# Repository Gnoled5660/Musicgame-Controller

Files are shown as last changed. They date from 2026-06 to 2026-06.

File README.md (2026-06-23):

# Musicgame-Controller

Controller_with_Case_2026-Jun-20_02-33-02PM-000_CustomizedView34039528250_png

# Description
This is an arcade like controller, designed for the Musicgame by bakedcloudz (GitHub Repo: https://github.com/wuelaineyuan-bit/MUSICGAME). It has four interactive buttons and one joystick. Next to these features, it also has a speaker on the side and a tft display. While the controller is inactive or is not being used, it will play a retro arcade like music in the background. All this is powered by a Raspberry Pi Pico 2.

# Motivation
The reason we designed this was because bakedcloudz project lacked of an interactive controller for her arcade game. Therefore, we wanted to design another controller for that project. This project is a sub project of the main project MUSICGAME (GitHub Repo: https://github.com/wuelaineyuan-bit/MUSICGAME). 

# PCB and Schematic
The PCB and schematic was made with KiCAD. Schematic is rather simple: Connect the pins to the buttons and joysticks. As almost every Pico 2 pin is a GPIO pin, almost every pin could be used to connect to the amplifier and tft module. 

Bildschirmfoto 2026-06-20 um 15 15 44

This PCB is a rather simple PCB, where the premade modules are soldered on top of it. There are no components that need to be preassembled. All the components are big enough to be soldered by hand. 

Bildschirmfoto 2026-06-20 um 15 12 18

This PCB is a two layer PCB, where the red tracks function as signal tracks and the blue tracks as power supply tracks.

Bildschirmfoto 2026-06-20 um 15 14 18

# Firmware
The firmware was written in micropython. Most of libraries are standard libraries provided by micropico. However, we had to download an external library for the tft display. The program begins with playing a retro music until one button is clicked. Then, it stops playing the music in a loop and starts listening to the actions that the user might take. Once a button or the joystick is pressed, it sends a message to the computer with the print() function. The other projects code has to read the lines with serial.readline() to decide which actions to make next.

# Assembling
There are a few components that need to be screwed on to the board. These components include the PCB, the joystick and the display. Because of that, we designed some holes, where heat threaded inserts can be placed. All components use M3 screws besides the joystick. The joystick requires M5 screws. The buttons can be simply pressed into the holes, which means it doesnt require any screws. 

Bildschirmfoto 2026-06-20 um 15 48 46

Bildschirmfoto 2026-06-20 um 15 49 10

Many components need to be soldered on to the PCB too. It is recommended to use header pins between the Pico 2 board and the PCB. After everything is soldered, you need the connection cables to connect the PCB with the buttons and joysticks. Another cable is used to connect the amplifier with the speaker.

Bildschirmfoto 2026-06-20 um 15 53 17

Depending on whether you want to color the music notes, there two versions of this controller. As a usual 3D printer cannot print two colors at the same time, the music notes have to be painted later by hand, if they should be colored black.

Bildschirmfoto 2026-06-19 um 22 34 00
Bildschirmfoto 2026-06-19 um 22 34 19

# Zine
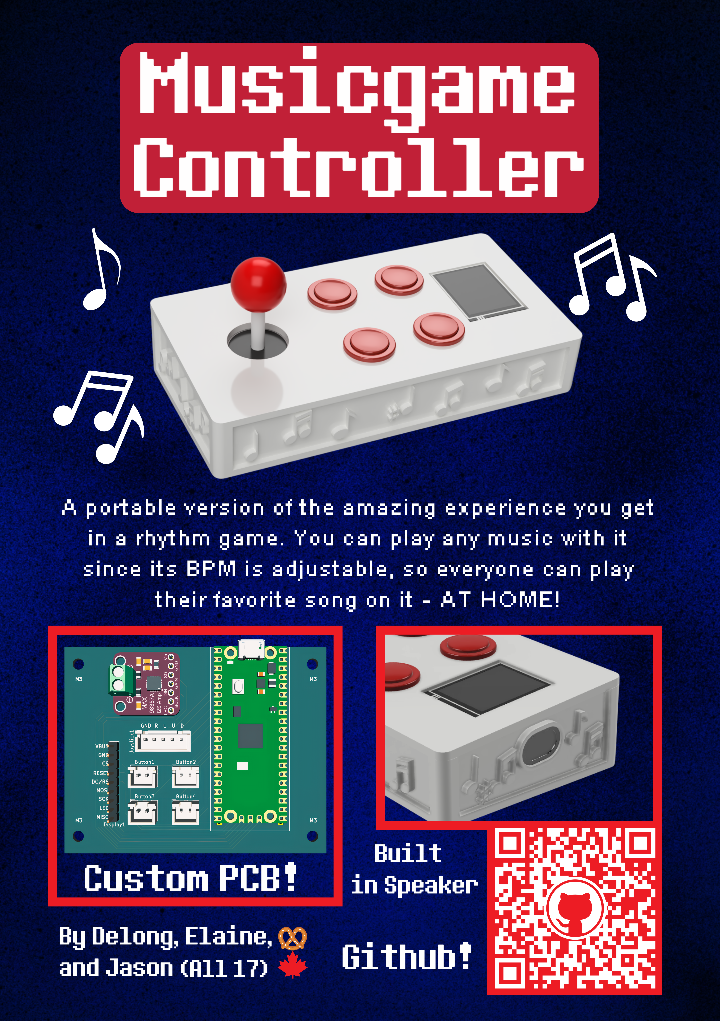
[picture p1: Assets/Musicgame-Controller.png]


# BOM
|Name |Description |Links |Quantity|Cost |
|---|---|---|---|-----|
|PCB |Printed Circuit Board |https://jlcpcb.com |1 |6 |
|Speaker |8Ohm 1W Speaker |https://botland.de/analoge-lautsprecher/19458-lautsprecher-1w-8ohm-30x20x5mm-adafruit-4227-5904422354848.html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 |1 |3.20 |
|MAX98357A |Amplifier |https://www.amazon.de/Verstärker-Verstärkerplatine-Elektronische-Enthusiasten-Ingenieure/dp/B0F1TRSD2N/ref=asc_df_B0F1TRSD2N?mcid=b3cc78920c783042ac17388eb574bcae&th=1&psc=1&tag=googshopde-21&linkCode=df0&hvadid=751200241164&hvpos=&hvnetw=g&hvrand=557849342057074083&hvpone=&hvptwo=&hvqmt=&hvdev=c&hvdvcmdl=&hvlocint=&hvlocphy=9192175&hvtargid=pla-2419607785174&psc=1&hvocijid=557849342057074083-B0F1TRSD2N-&hvexpln=0|1 |8 |
|Pico 2 |Microcontroller |https://www.reichelt.de/de/de/shop/produkt/raspberry_pi_pico_2_rp235x_cortex-m33_microusb-383358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 |1 |5.14 |
|Arcade Button |Button |https://www.berrybase.de/mini-arcade-button-24mm/farbe-rot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 |4 |4.13 |
|Joystick |Joystick to control direction|https://de.aliexpress.com/item/1005006881757851.html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€%214%2C69€%21%21%21%21%21%40211b6c1717819569630011453e4670%2112000038607187018%21btfpre%21%21%21%211%210%21&pvid=210f2bc9-ea8b-413f-9403-466b57ef5987&afTraceInfo=1005006881757851__pc__c_ppc_item_bridge_pc_same_wf__r6YWpYS__1781956963362&gatewayAdapt=glo2deu |1 |12.61|
|5 Pin JST-XH |Receptacle for Joystick |https://www.reichelt.de/de/de/shop/produkt/jst_-_stiftleiste_gerade_1x5-polig_-_xh-185076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 |1 |0.34 |
|2 Pin JST-XH |Receptacle for Buttoms |https://www.berrybase.de/ph2.0-buchse-printmontage-gerade-2-pin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 |4 |0.46 |
|2 Pin JST-XH cable |Cable |https://www.berrybase.de/kabel-mit-jst-xh-2.54mm-steckverbinder-awg26-20cm/pinanzahl-2-pin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 |4 |1.60 |
|5 Pin JST-XH cable |Cable |https://www.berrybase.de/kabel-mit-jst-xh-2.54mm-steckverbinder-awg26-20cm/pinanzahl-5-pin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 |1 |0.57 |
|Header Pin |2.54mm Header Pin |https://www.digikey.de/de/products/detail/amphenol-icc-fci-/10129378-920003BLF/7915971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 |1 |0.52 |
|Heated threaded inserts|M3x4mmx5mm |https://www.berrybase.de/bossard-bn1052-gewindeeinsatz-messing-m3-laenge-5-8mm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 |8 |2.58 |
|Heated threaded inserts|M5x9mmx5mm |https://www.berrybase.de/bossard-bn1052-gewindeeinsatz-messing-m5-laenge-9-5mm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 |4 |1.28 |
|M3 |screws |https://www.berrybase.de/makerbeam-linsenkopfschrauben-fuer-15x15-makerbeamxl-openbeam-m3x6mm-innensechskant-100-stueck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 |8 |6 |
|M5 |screws |https://www.thomann.de/de/km_m5_rack_screw_pack.htm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 |4 |4 |
|Filament |Whole Case | |1 |8.93 |
|total | | | |63.19|

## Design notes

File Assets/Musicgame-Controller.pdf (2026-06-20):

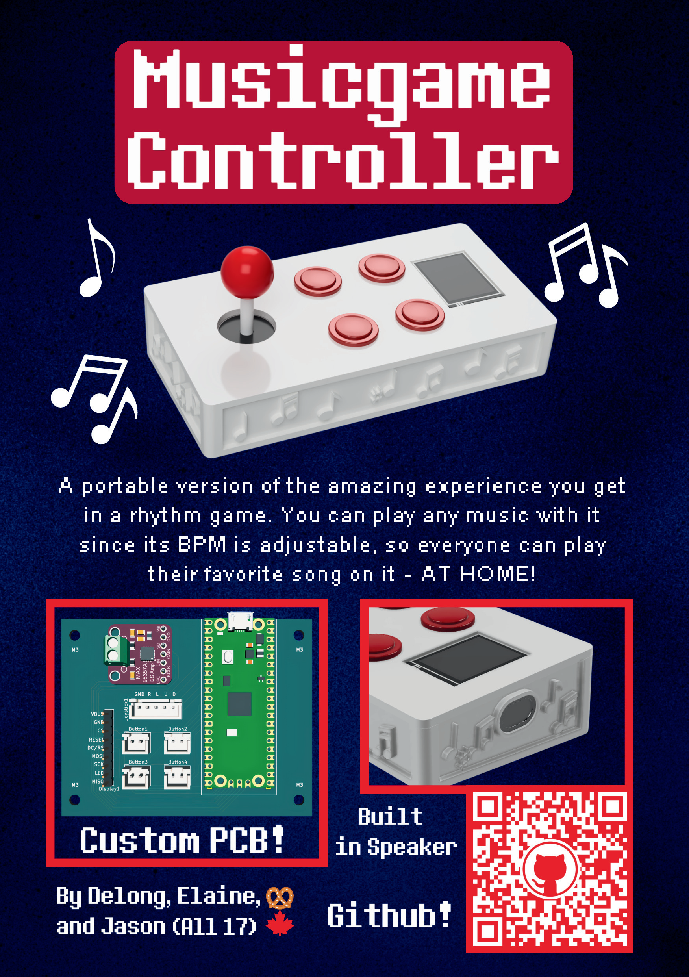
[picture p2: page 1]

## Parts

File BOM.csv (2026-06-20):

Name | Description | Links | Quantity | Cost
PCB | Printed Circuit Board | https://jlcpcb.com | 1 | 6
Speaker | 8Ohm 1W Speaker | https://botland.de/analoge-lautsprecher/19458-lautsprecher-1w-8ohm-30x20x5mm-adafruit-4227-5904422354848.html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 | 1 | 3.20
MAX98357A | Amplifier | https://www.amazon.de/Verstärker-Verstärkerplatine-Elektronische-Enthusiasten-Ingenieure/dp/B0F1TRSD2N?mcid=b3cc78920c783042ac17388eb574bcae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 | 1 | 8
Pico 2 | Microcontroller | https://www.reichelt.de/de/de/shop/produkt/raspberry_pi_pico_2_rp235x_cortex-m33_microusb-383358?PROVID=2788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 | 1 | 5.14
Arcade Button | Button | https://www.berrybase.de/mini-arcade-button-24mm/farbe-rot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 | 4 | 4.13
Joystick | Joystick to control direction | https://de.aliexpress.com/item/1005006881757851.html | 1 | 12.61
5 Pin JST-XH | Receptacle for Joystick | https://www.reichelt.de/de/de/shop/produkt/jst_-_stiftleiste_gerade_1x5-polig_-_xh-185076?PROVID=2788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 | 1 | 0.34
2 Pin JST-XH | Receptacle for Buttoms | https://www.berrybase.de/ph2.0-buchse-printmontage-gerade-2-pin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 | 4 | 0.46
2 Pin JST-XH cable | Cable | https://www.berrybase.de/kabel-mit-jst-xh-2.54mm-steckverbinder-awg26-20cm/pinanzahl-2-pin?gad_source=1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 | 4 | 1.60
5 Pin JST-XH cable | Cable | https://www.berrybase.de/kabel-mit-jst-xh-2.54mm-steckverbinder-awg26-20cm/pinanzahl-5-pin?gad_source=1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 | 1 | 0.57
Header Pin | 2.54mm Header Pin | https://www.digikey.de/de/products/detail/amphenol-icc-fci-/10129378-920003BLF/7915971?gclsrc=aw.ds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 | 1 | 0.52
Heated threaded inserts | M3x4mmx5mm | https://www.berrybase.de/bossard-bn1052-gewindeeinsatz-messing-m3-laenge-5-8mm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 | 8 | 2.58
Heated threaded inserts | M5x9mmx5mm | https://www.berrybase.de/bossard-bn1052-gewindeeinsatz-messing-m5-laenge-9-5mm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 | 4 | 1.28
M3 | screws | https://www.berrybase.de/makerbeam-linsenkopfschrauben-fuer-15x15-makerbeamxl-openbeam-m3x6mm-innensechskant-100-stueck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 | 8 | 6
M5 | screws | https://www.thomann.de/de/km_m5_rack_screw_pack.htm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 | 4 | 4
Filament | Whole Case |  | 1 | 8.93
total |  |  |  | 63.19

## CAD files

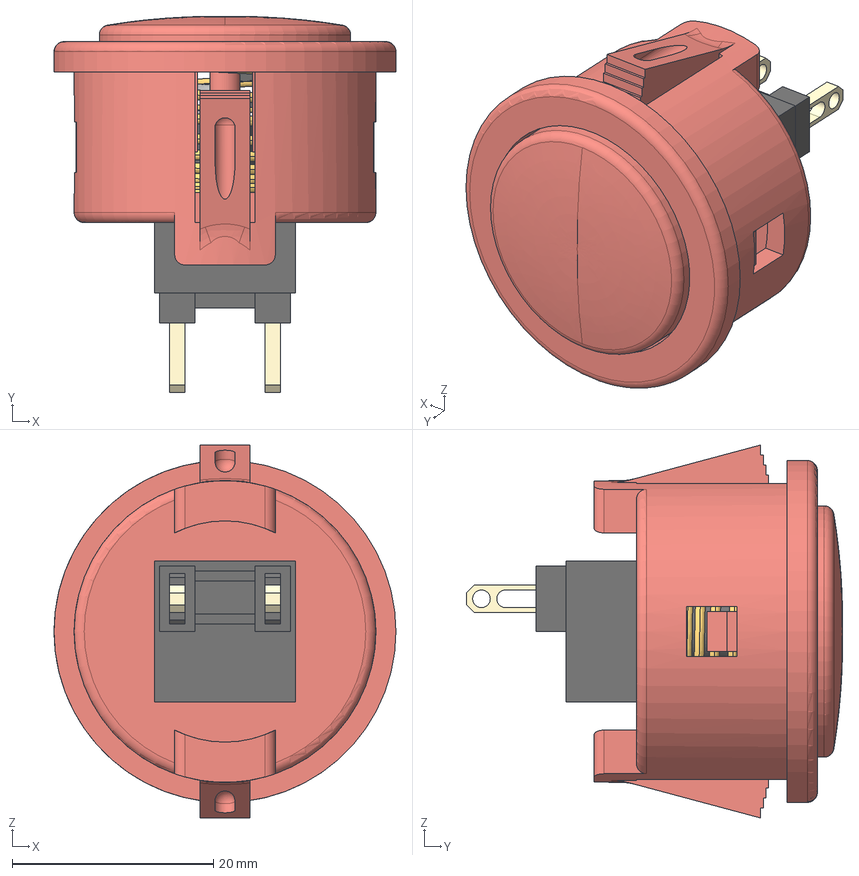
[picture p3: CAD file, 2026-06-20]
CAD/sanwa_button_00_asm v3.step
34.0 x 37.4 x 37.1 mm
SANWA_BUTTON_00
BLACK_00
SANWA_BUTTON_02
SPRING_4U_AF0

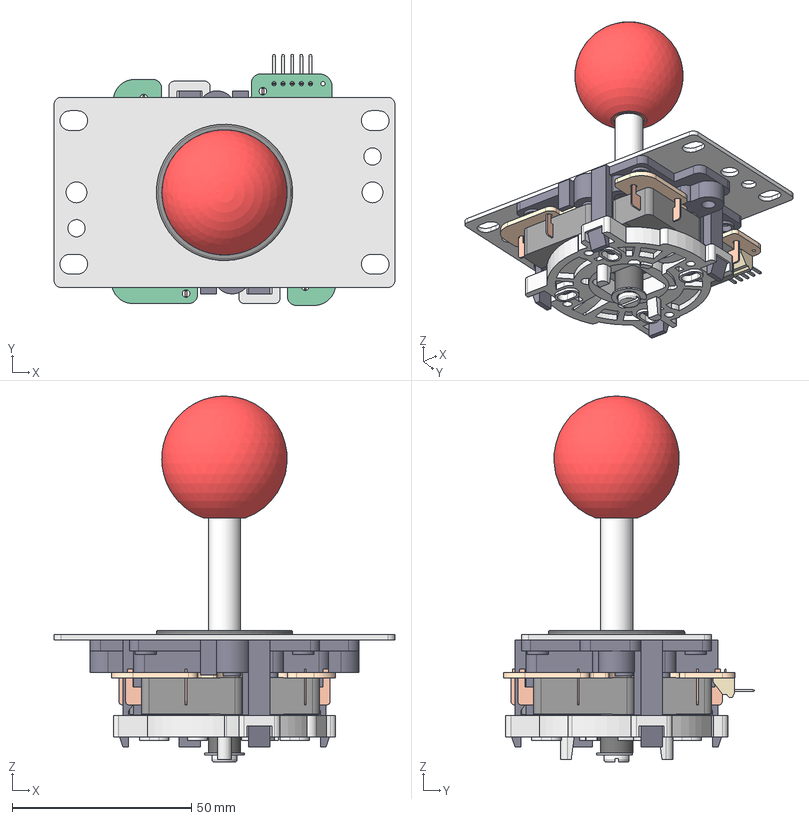
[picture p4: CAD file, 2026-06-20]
CAD/Sanwa JLF-TP-8YT 4-8Gate v1.step
95.0 x 69.9 x 102.0 mm
Connector 5P
JLF-P1 Mounting Plate
Sanwa LB-35 Balltop Dark Red
Sanwa JL-S9F Shaft
Solo Sanwa JLF Dustwasher
Sanwa LB-30 N-S Battop Adapter
Sanwa JLF P-2 Main Body
Sanwa JLF-P-4 Pivot
Push Button Arcade
Push Button Arcade_clne150
Push Button Arcade_clne151
Push Button Arcade_clne152
Sanwa JLF Actuator
Circlip
Sanwa JLF-P-6 Pressure Spring Base
Sanwa TP-MA PCB
Sanwa JLF-MW Washer
Sanwa JLF Spring
Sanwa GT-8F 4/8-Way Restrictor Plate
M3x10-Screw
M3x10-Screw001
M3x10-Screw002
M3x10-Screw003
M3-Nut
M3-Nut004
M3-Nut007
M3-Nut006
Sanwa GT Restrictor Plate

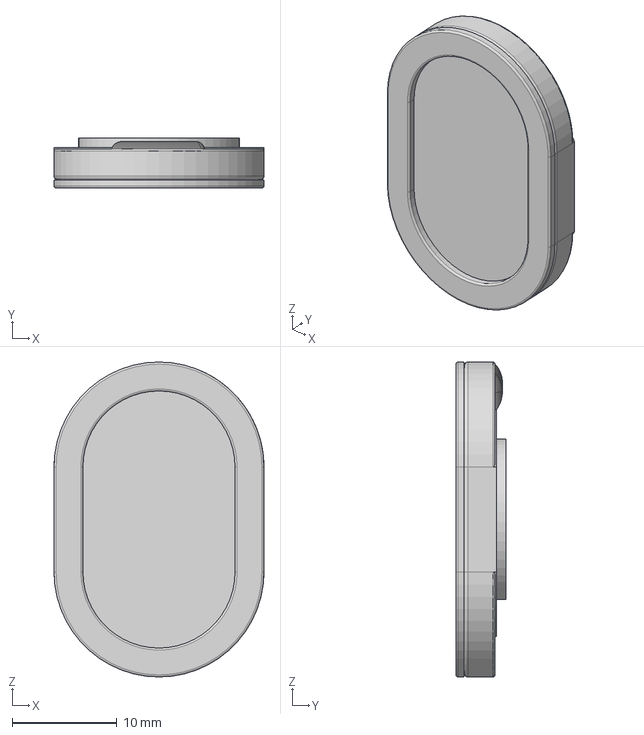
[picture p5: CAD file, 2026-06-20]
CAD/Speaker (1) v1.step
20.0 x 4.80 x 30.0 mm

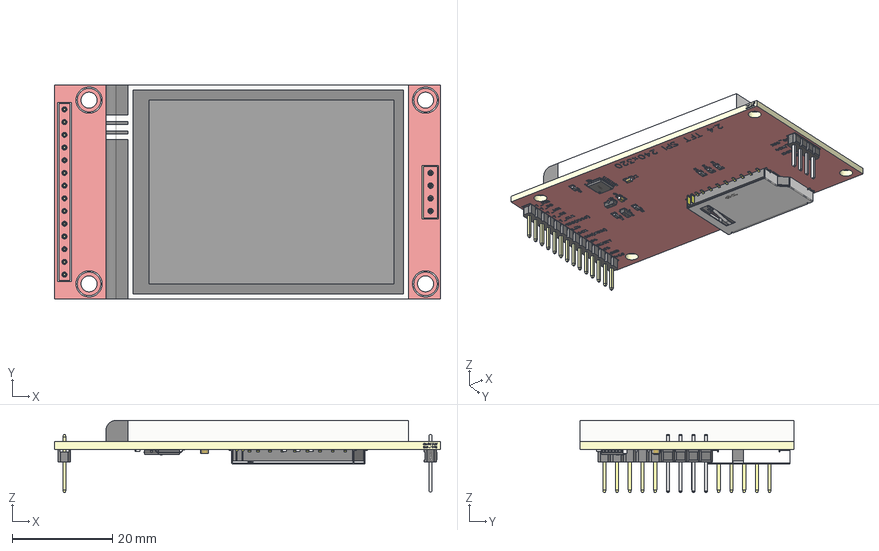
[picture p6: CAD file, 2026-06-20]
CAD/TFT LCD 2.4 inch ILI9341 touch v1.step
77.2 x 42.7 x 14.4 mm
Board~HwOR
TopSilkscreen~HwOR
BottomSilkscreen~HwOR
R0603~R0603~HwOR x 6
C0603~C0603_L1.6-W0.8-H0.8~HwOR x 2
HDR-TH_4P-P2.54-V-M~HDR-TH_4P-P2.54-M-LI-1X4P~HwOR
CONN-TH_PZ254V-11-14P~CONN-TH_PZ254V-11-14P~HwOR
SOT-23-3_L2.9-W1.3-P1.90-LS2.4-BR~SOT-23-3P_L2.9-W1.3-H1.0-LS2.4-P0.9 5~HwOR x 2
SD-CARD-SMD_SD-CARD-11P~SD-CARD-SMD_SD-CARD-11P~HwOR
TSSOP-16_L5.0-W4.4-P0.65-LS6.4-BL~TSSOP-16_L5.0-W4.4-H1.0-LS6.4-P0.65 ~HwOR
text

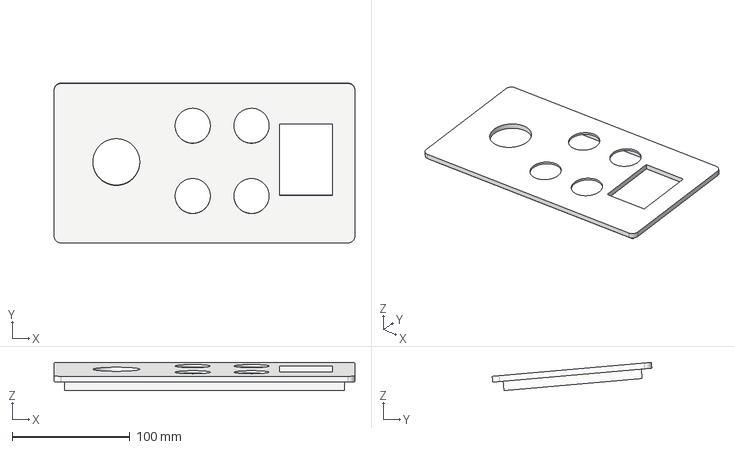
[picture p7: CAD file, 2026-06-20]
CAD/Case Top.step
256.0 x 135.9 x 24.0 mm

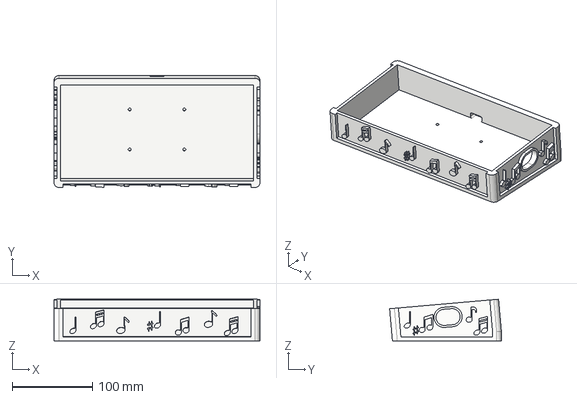
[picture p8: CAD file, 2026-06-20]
CAD/Case Bottom.step
256.0 x 139.0 x 51.7 mm

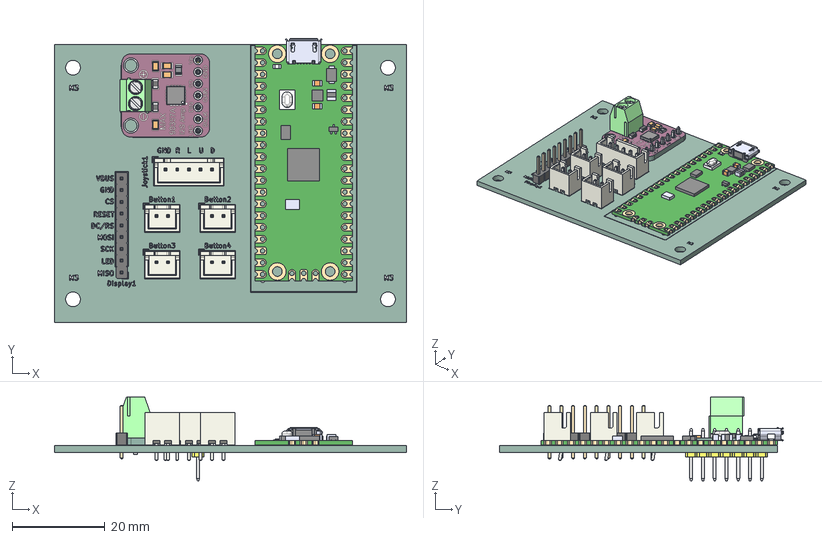
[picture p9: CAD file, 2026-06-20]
CAD/Controller.step
76.0 x 61.3 x 18.0 mm
JST_B2B_XH_A x 4
SC0915
JST_B5B_XH_A
PinHeader_1x09_P254mm_Vertical
PCB
M1.6x4-Screw030
0805 Ferrite v1 x 2
Header
Controller_silkscreen
Controller_PCB

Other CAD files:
CAD/Controller with Case Music Notes colored.f3z
CAD/Controller with Case No color.f3z

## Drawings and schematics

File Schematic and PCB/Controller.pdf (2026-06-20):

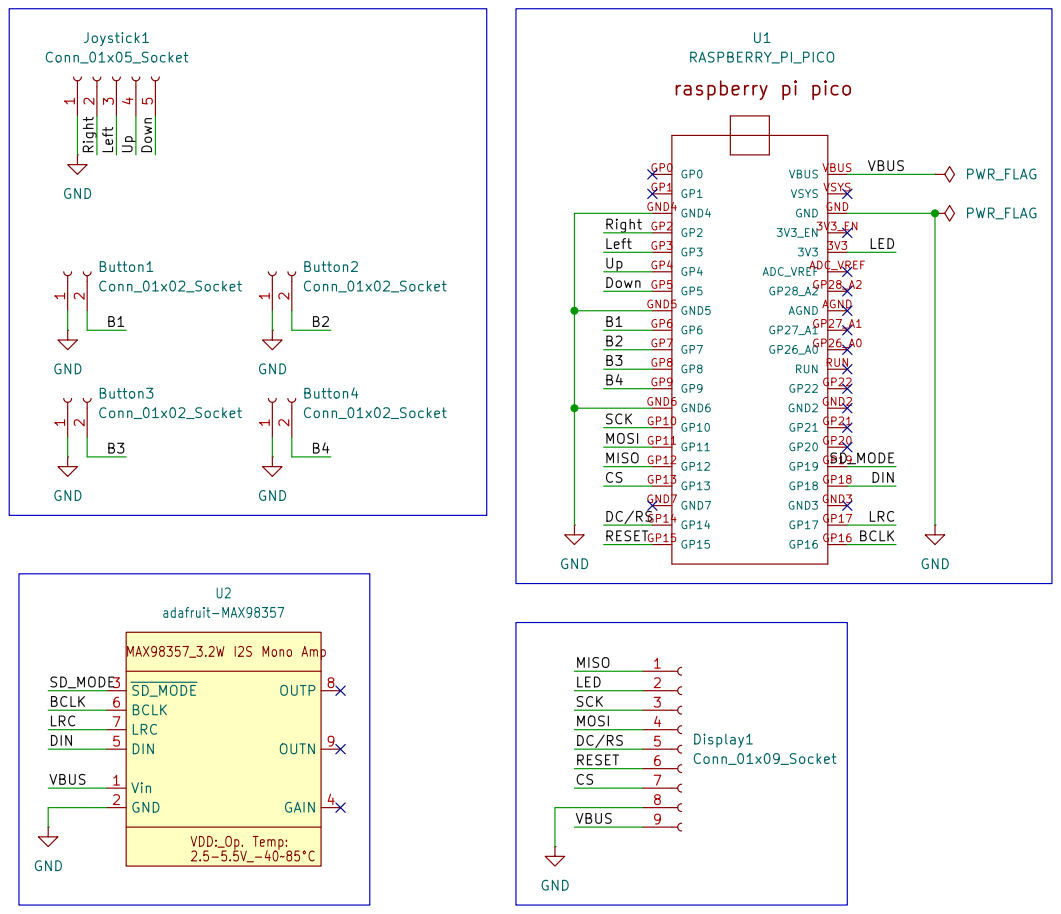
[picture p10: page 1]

Size: A4 | Rev: v1
KiCad E.D.A. 10.0.3 | Id: 1/1

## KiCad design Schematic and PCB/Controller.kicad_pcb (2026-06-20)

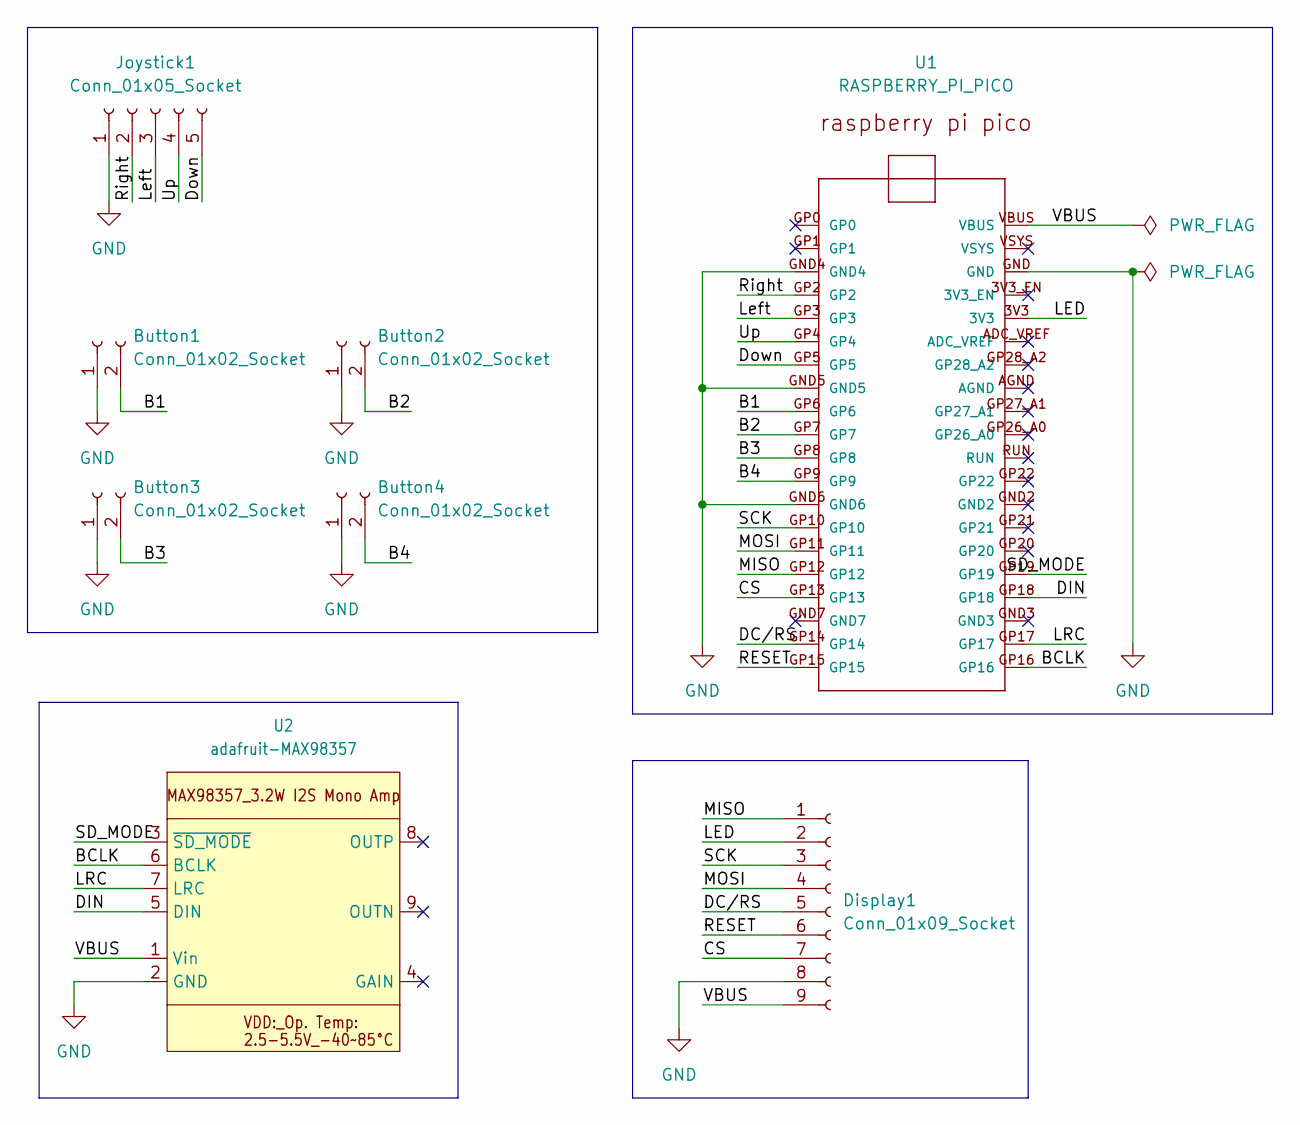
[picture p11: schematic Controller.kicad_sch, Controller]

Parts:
Button1, Button2, Button3, Button4: Conn_01x02_Socket; JST_XH_B2B-XH-A_1x02_P2.50mm_Vertical
Display1: Conn_01x09_Socket; PinHeader_1x09_P2.54mm_Vertical
Joystick1: Conn_01x05_Socket; JST_XH_B5B-XH-A_1x05_P2.50mm_Vertical
U1: RASPBERRY_PI_PICO
U2: adafruit-MAX98357

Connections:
/B1: Button1.2, U1.GP6
/B2: Button2.2, U1.GP7
/B3: Button3.2, U1.GP8
/B4: Button4.2, U1.GP9
/BCLK: U1.GP16, U2.6 (BCLK)
/CS: Display1.7, U1.GP13
/DC/RS: Display1.5, U1.GP14
/DIN: U1.GP18, U2.5 (DIN)
/Down: Joystick1.5, U1.GP5
/LED: Display1.2, U1.3V3
/LRC: U1.GP17, U2.7 (LRC)
/Left: Joystick1.3, U1.GP3
/MISO: Display1.1, U1.GP12
/MOSI: Display1.4, U1.GP11
/RESET: Display1.6, U1.GP15
/Right: Joystick1.2, U1.GP2
/SCK: Display1.3, U1.GP10
/SD_MODE: U1.GP19, U2.3 (~SD_MODE)
/Up: Joystick1.4, U1.GP4
/VBUS: Display1.9, U1.VBUS, U2.1 (Vin)
GND: Button1.1, Button2.1, Button3.1, Button4.1, Display1.8, Joystick1.1, U1.GND, U1.GND4, U1.GND5, U1.GND6, U2.2 (GND)

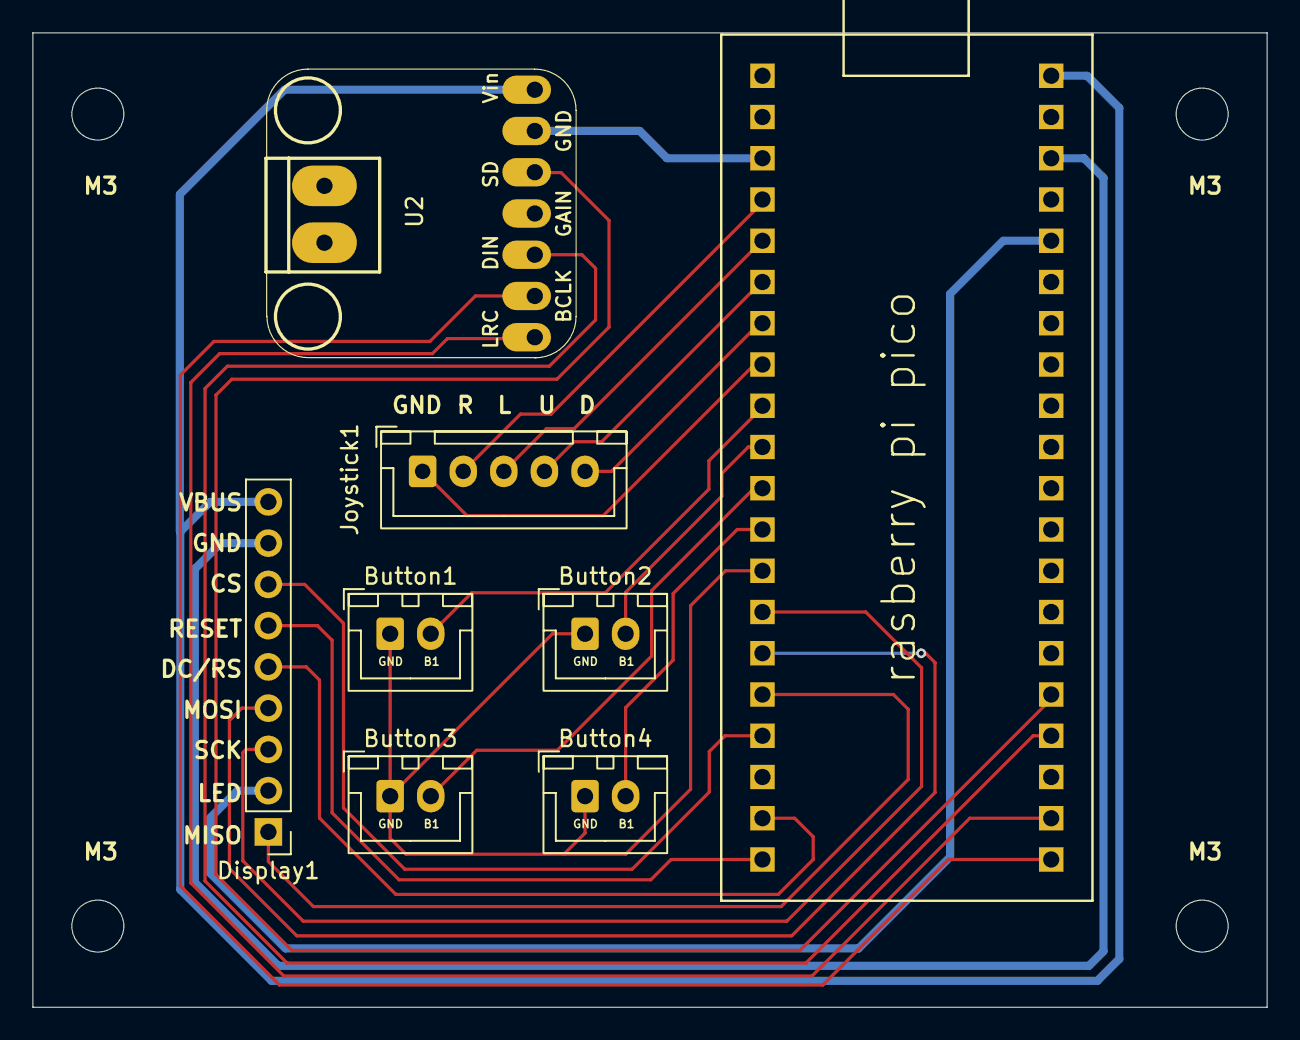
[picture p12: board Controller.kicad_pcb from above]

Board: 2 copper layers, 76.0 x 60.0 mm, 8 parts (0 on the bottom side), 21 nets.

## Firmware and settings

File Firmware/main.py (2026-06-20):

from machine import Pin, I2S, SPI
from ili9341 import Display, color565
from utime import sleep

#buttons
button1 = Pin(6, Pin.IN, Pin.PULL_UP)
button2 = Pin(7, Pin.IN, Pin.PULL_UP)
button3 = Pin(8, Pin.IN, Pin.PULL_UP)
button4 = Pin(9, Pin.IN, Pin.PULL_UP)

#jotstick
joystick_right = Pin(2, Pin.IN, Pin.PULL_UP)
joystick_left = Pin(3, Pin.IN, Pin.PULL_UP)
joystick_up = Pin(4, Pin.IN, Pin.PULL_UP)
joystick_down = Pin(5, Pin.IN, Pin.PULL_UP)

#amplifier
sd_mode = Pin(19, Pin.OUT)
sd_mode.value(1)
i2s = I2S(0, sck=Pin(16), ws=Pin(17), sd=Pin(18), mode=I2S.TX, bits=16, format=I2S.STEREO, rate=44100, ibuf=40000)

#tft display
spi = SPI(1, baudrate=40_000_000, sck=Pin(10), mosi=Pin(11))
display = Display(spi, cs=Pin(13), dc=Pin(14), rst=Pin(15))

white = color565(255, 255, 255)
black = color565(0, 0, 0)
green = color565(0, 255, 0)

display.clear()
display.draw_text8x8(10, 10, "Arcade Panel", white)

def display_write_line(y, text):
    display.fill_rectangle(10, y, 220, 8, black)
    display.draw_text8x8(10, y, text, green)

def play_music(filename, stop_button):
    while True:
        with open(filename, "rb") as f:
            f.seek(44)
            while True:
                data = f.read(2048)
                if not data:
                    break
                if stop_button.value() == 0:
                    while stop_button.value() == 0: #wait until button is released
                        sleep(0.01)
                    return
                i2s.write(data)

last_button1 = 1
switch = False
counter = 0

while True:
    current = button1.value()

    if current == 0 and last_button1 == 1:
        display_write_line(40, "Playing music...")
        play_music("retromsuic.wav", button1)
        display_write_line(40, "Music was stopped")
    last_button1 = current
        
    if button2.value() == 0:
        display_write_line(40, "This button does nothing but counting")
        counter += 1
        display_write_line(20, f"{counter}")

    elif button3.value() == 0:
        print("BUTTON1")
    elif button4.value() == 0:
        print("BUTTON2")
    
    if joystick_right.value() == 0:
        print("RIGHT")
    elif joystick_left.value() == 0:
        print("LEFT")
    elif joystick_up.value() == 0:
        print("UP")
    elif joystick_down.value() == 0:
        print("DOWN")   
    sleep(0.05)

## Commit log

2026-06-20 Rename Bottom Case.step to Case Bottom.step
    [Case Bottom.step]
2026-06-20 Rename Top Case.step to Case Top.step
    [Case Top.step]
2026-06-20 Rename Unbenannte Tabelle - Tabellenblatt1-2.csv to BOM.csv
    [BOM.csv]
2026-06-20 Update PCB assembly instructions in README
    Added instructions for connecting cables after soldering components.
